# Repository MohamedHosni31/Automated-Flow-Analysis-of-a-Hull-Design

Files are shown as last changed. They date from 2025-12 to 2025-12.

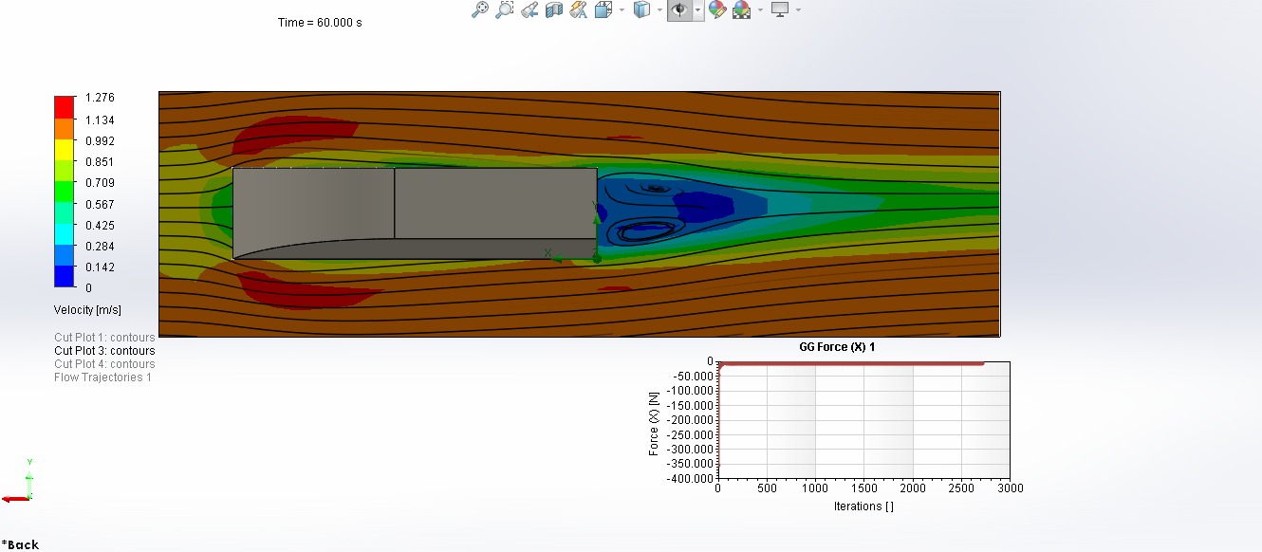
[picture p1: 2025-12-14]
2nd.jpg

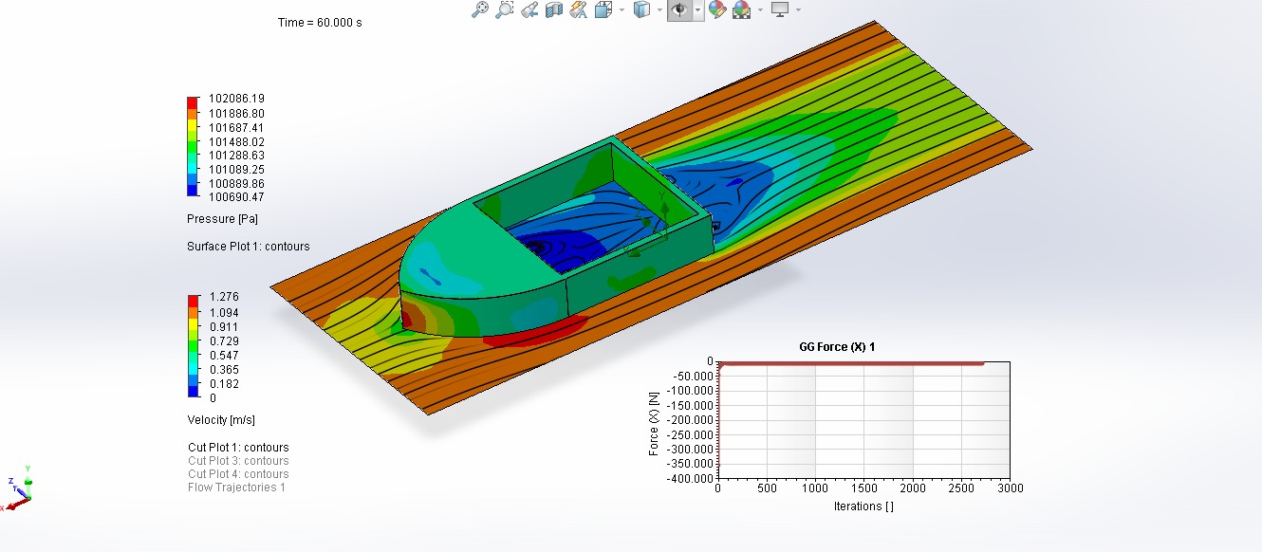
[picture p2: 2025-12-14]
1st.jpg

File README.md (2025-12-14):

# Automated Flow Analysis of a Hull Design

## 📌 Project Overview
This project involves the design and automated flow analysis of a small boat hull to evaluate fluid behavior around the structure. The project was developed at Alexandria University to demonstrate fundamental concepts of fluid mechanics, flow visualization, and design automation.

## 🎓 Academic Context
- Institution: Alexandria University
- Project Type: Mechanical Engineering Academic Project

## 🛠 Tools & Software
- SolidWorks
- SolidWorks Flow Simulation
- DC Motor (Propulsion Concept)

## ⚙ System Description
- Designed a small-scale boat hull capable of carrying a beverage can.
- Integrated a DC motor concept to enable forward motion.
- Performed flow analysis to study fluid behavior around the hull.
- Automated flow simulations to visualize pressure and velocity distribution.
- Evaluated hydrodynamic performance based on flow results.

## 📊 Key Outcomes
- Successful hull design with stable buoyancy.
- Visualization of flow patterns around the hull.
- Pressure and velocity distribution analysis.
- Demonstrated the impact of hull geometry on fluid flow.

## 📂 Project Contents
- Hull CAD model
- Flow simulation results
- Screenshots and visual outputs
- Project documentation

## 🎯 Skills Demonstrated
Fluid Mechanics · Flow Simulation · SolidWorks · Hull Design · Engineering Analysis · Automation

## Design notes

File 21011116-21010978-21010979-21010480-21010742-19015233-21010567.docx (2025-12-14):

Designing a Model Ship

NORMANDY 2

Presented By:

كريم ايهاب حمادة عبد الرؤوف 21010979

محمد حسني محمد ابراهيم 21011116

كريم السيد محمد محمد سريح 21010978

حنين اسامة محمد احمد 21010480

عبدالرحمن سيد احمد كامل 21010742

احمد رضا بسيوني السيد 19015233

زياد حسام محمد السعيد عثمان 21010567

Presented To:

Dr. Yasser Abuouf

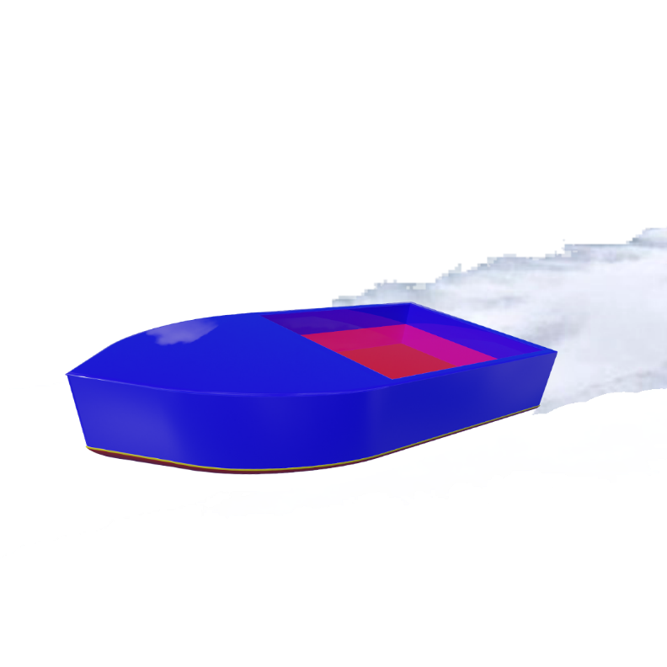
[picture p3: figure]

# Abstract

As it is required to build a ship with the ability to carry a standard cargo load of 1 can of soft drink (330ml) and must be stable in both cases loaded or unloaded. As a cooperative team, we fulfilled the requirements with an extraordinary outcome “Normandy 2”.

# Design Evolution

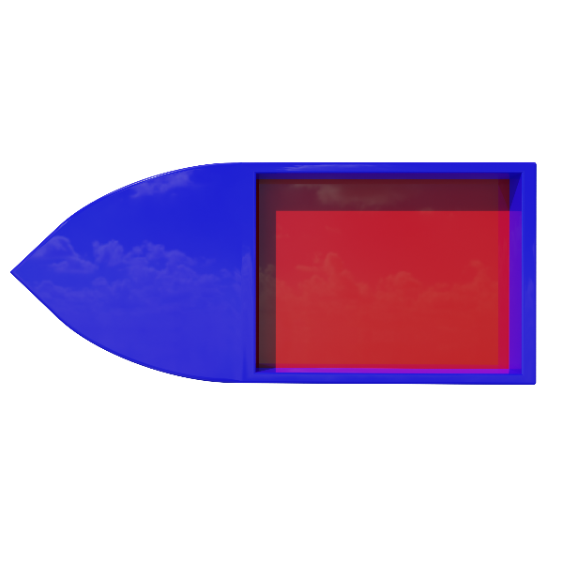
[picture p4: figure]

Phases were tackled by the team members to develop a fruitful result beginning with brainstorming and collaboration where we shared our ideas and developed them together followed by the illumination phase where we put the strategy, the costs, material selection, and the timeline to get the work done due to the set deadline. As everything comes to an end, implementation was our last to make ideas real and test the creation.

# Frame Design

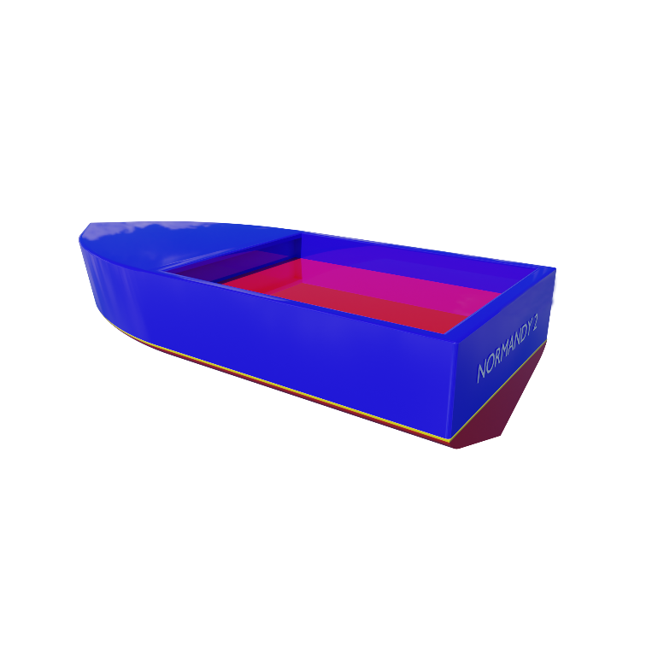
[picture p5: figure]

The boat’s frame was carefully designed to be stable loaded and unloaded. For fixations, a squared groove was made to maintain the components. The unloaded boat’s dimensions are 36 cm in length and 20 cm in width, 1598.16883 cm³ in volume, and 3689.3515 cm² in area, where its height from the hull to the waterline is 1.4 cm. These dimensions include the likes of the motor, the propeller, and the battery. When the can is included the height of the water line increases to 2.6 cm.

# Material Selection

Foam has proved its ability in compromising strength to hold the load and other components and being stable while loaded and unloaded. Foam appeared to be the most cost-effective compared to other materials such as wood or plastic polymers.

# Calculations

Immersed Volume :

Unloaded :

Boat Mass = 470 grams, Seawater Density = 1030 kg/m³, Immersed Height = 1.4 cm

Volume_(immersed) × ρ_(fluid) =Volume_(body) × ρ_(solid)

V_(imm) =(m_(body))/(ρ_(fluid))=0.47/1030

V_(imm) =4.56 × 10^(-4) m^3

Loaded :

Boat Mass = 840 grams, Seawater Density = 1030 kg/m³, Immersed Height = 2.6 cm

Volume_(immersed) × ρ_(fluid) =Volume_(body) × ρ_(solid)

V_(imm) =(m_(body))/(ρ_(fluid))=0.84/1030

V_(imm) =8.155 × 10^(-4) m^3

Stability Check :

Unloaded :

Boat Mass = 470 grams, Center of Gravity (From Solidworks) = 50 mm

Center of Buoyancy (From Solidworks) = 12.48 mm, Volume immersed = 4.56 x 10^(-4) m^3

Second moment of area (From Solidworks) = 197200620.36 mm⁴

BG=KG-KB=50-12.48

BG=37.52 mm

BM=I/(V_(imm))=(197200620.36 × (10^(-3) )^4)/(4.56 × 10^(-4))

BM=0.432 m=432.46 mm

BM>BG → ∴Boat is stable

Loaded :

Boat Mass = 840 grams, Center of Gravity (From Solidworks) = 50 mm

Center of Buoyancy (From Solidworks) = 22 mm, Volume immersed = 8.16 x 10^(-4) m^3

Second moment of area (From Solidworks) = 143052480.16 mm⁴

BG=KG-KB=50-22

BG=28 mm

BM=I/(V_(imm))=(143052480.16 × (10^(-3) )^4)/(8.16 × 10^(-4))

BM=0.175 m=175.42 mm

BM>BG → ∴Boat is stable

Ship Resistance (Drag Force) :

Unloaded :

Seawater Density = 1030 kg/m³, Velocity (Calculated after trials) = 0.4667609 m/s,

Wetted Area = 0.11401175 m², Water’s Kinematic Viscosity = 1 mm²/s

Re=(Velocity × Length)/(Kinematic viscosity)=(0.4667609×0.36)/(1 × 10^(-6))=168033.924

Resistance coefficient=0.075/((log_10 Re-2)^2)=7.2 × 10^(-3)

Resistance=Cf ×1/2 × ρ × v^2 × A_(imm)

Res=7.2 × 10^(-3) ×1/2 × 1030 × 0.4667609^2 ×0.11401175

Resistance=0.0921 N

Loaded :

Seawater Density = 1030 kg/m³, Velocity (Calculated after trials) = 0.37362729 m/s,

Wetted Area = 0.18644327 m², Water’s Kinematic Viscosity = 1 mm²/s

Re=(Velocity × Length)/(Kinematic viscosity)=(0.37362729×0.36)/(1 × 10^(-6))=134505.82

Resistance coefficient=0.075/((log_10 Re-2)^2)=7.66 × 10^(-3)

Resistance=Cf ×1/2 × ρ × v^2 × A_(imm)

Res=7.66 x 10^(-3) ×1/2 × 1030 × 0.37362729^2 × 0.18644327

Resistance=0.1027 N

Flow Simulation :


Drag Force = 0.09 Newtons

Cost Analysis

Component | Description | Status | Cost
Foam sheet | 142 gm | New | 300.0
Dc motor | Dc motor with gearbox 9V | New | 140.0
Battery | Camelion battery 9V 6F22 | New | 20.0
Battery cap | Battery cap 9V | New | 2.0
Propeller | Red plastic 4 blades propeller | New | 15.0
Switch | On/off red switch 3 pins 6A 250VAC 15x21mm | New | 2.0
| | | 479.0

Technical report Normandy 2

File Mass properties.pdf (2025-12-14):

Mass properties of Untitled.step Configuration: Default
Coordinate system: Coordinate System1

Mass = 313.07 grams

Volume = 1598168.83 cubic millimeters

Surface area = 368935.15 square millimeters

Center of mass: ( millimeters )
X = 0.00
Y = 48.69
Z = -157.03

Principal axes of inertia and principal moments of inertia: ( grams * square millimeters ) Taken at the center of mass.
Ix = ( 0.00, -0.04, 1.00) | Px = 1358303.16
Iy = ( 1.00, 0.00, 0.00) | Py = 3524942.91
Iz = ( 0.00, 1.00, 0.04) | Pz = 4413985.74

Moments of inertia: ( grams * square millimeters )
Taken at the center of mass and aligned with the output coordinate system. (Using positive tensor notation.)
Lxx = 3524942.91 | Lxy = 7.56Lxz = -39.52
Lyx = 7.56 Lyy = 4408124.89 | Lyz = -133695.74
Lzx = -39.52 | Lzy = -133695.74 | Lzz = 1364164.01

Moments of inertia: ( grams * square millimeters )
Taken at the output coordinate system. (Using positive tensor notation.)
Ixx = 11987176.84 | Ixy = -16.52 | Ixz = 38.15
Iyx = -16.52 | Iyy = 12128183.67 Iyz = -2527361.51
Izx = 38.15 | Izy = -2527361.51 | Izz = 2106339.17

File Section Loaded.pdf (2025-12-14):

Section properties of the selected face of Ship

Area = 62917.32 millimeters^2

Centroid relative to output coordinate system origin: ( millimeters ) X = 159.42
Y = 26.00
Z = 0.00

Moments of inertia of the area, at the centroid: ( millimeters ^ 4 ) Lxx = 188050419.75 Lxy = 0.00Lxz = 0.00 Lyx = 0.00 Lyy = 746043565.69 Lyz = 0.00 Lzx = 0.00Lzy = 0.00Lzz = 557993145.94

Polar moment of inertia of the area, at the centroid = 746043565.69 millimeters ^ 4

Angle between principal axes and part axes = 90.00 degrees

Principal moments of inertia of the area, at the centroid: ( millimeters ^ 4 )
Ix = 188050419.75
Iy = 557993145.94

Moments of inertia of the area, at the output coordinate system: ( millimeters ^ 4 )
LXX = 230582529.02 | LXY = 260783404.69LXZ = 0.00
LYX = 260783404.69 LYY = 2345023379.26 | LYZ = 0.00
LZX = 0.00 | LZY = 0.00 | LZZ = 2199505068.79

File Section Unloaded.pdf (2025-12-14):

Section properties of the selected face of 1

Area = 20454.29 millimeters^2

Centroid relative to assembly origin: ( millimeters ) X = -0.02
Y = 35.42
Z = 80.72

Moments of inertia of the area, at the centroid: ( millimeters ^ 4 ) Lxx = 197200620.36 Lxy = 0.00Lxz = -73834.95 Lyx = 0.00 Lyy = 287529577.91 Lyz = 0.00
Lzx = -73834.95 Lzy = 0.00Lzz = 90328957.56

Polar moment of inertia of the area, at the centroid = 287529577.91 millimeters ^ 4

Angle between principal axes and assembly coordinate axes = 0.04 degrees

Principal moments of inertia of the area, at the centroid: ( millimeters ^ 4 )
Ix = 90328906.55
Iy = 197200671.37

Moments of inertia of the area, at the output coordinate system: ( millimeters ^ 4 )
LXX = 356147207.57 | LXY = -12553.95 | LXZ = 45226.00
LYX = -12553.95 | LYY = 420811869.72 LYZ = 58485868.12
LZX = 45226.00 | LZY = 58485868.12 LZZ = 115993265.24

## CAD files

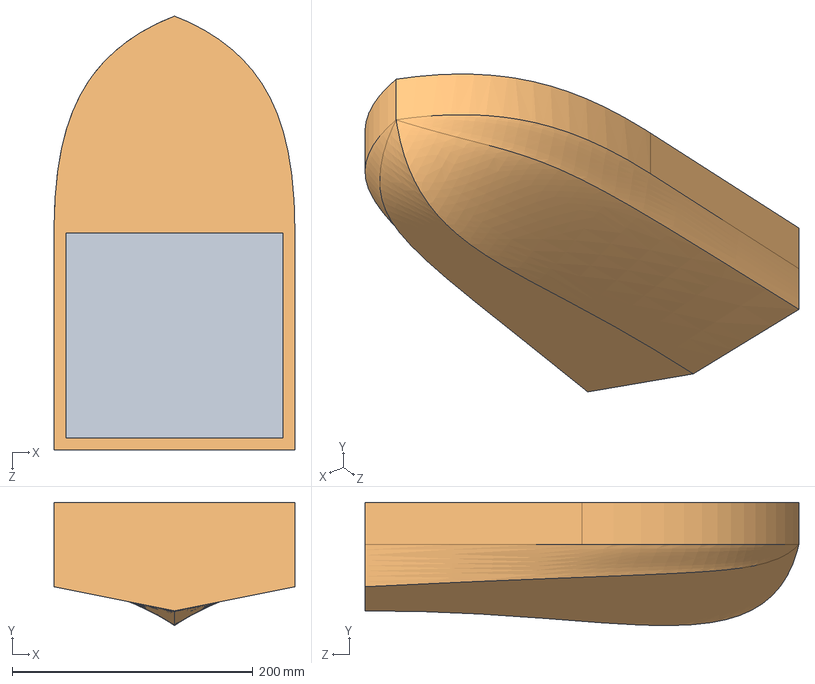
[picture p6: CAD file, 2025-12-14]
model.SLDASM
200.0 x 102.3 x 360.0 mm
Component1.step
(Unsaved).step
(Unsaved)-0.step

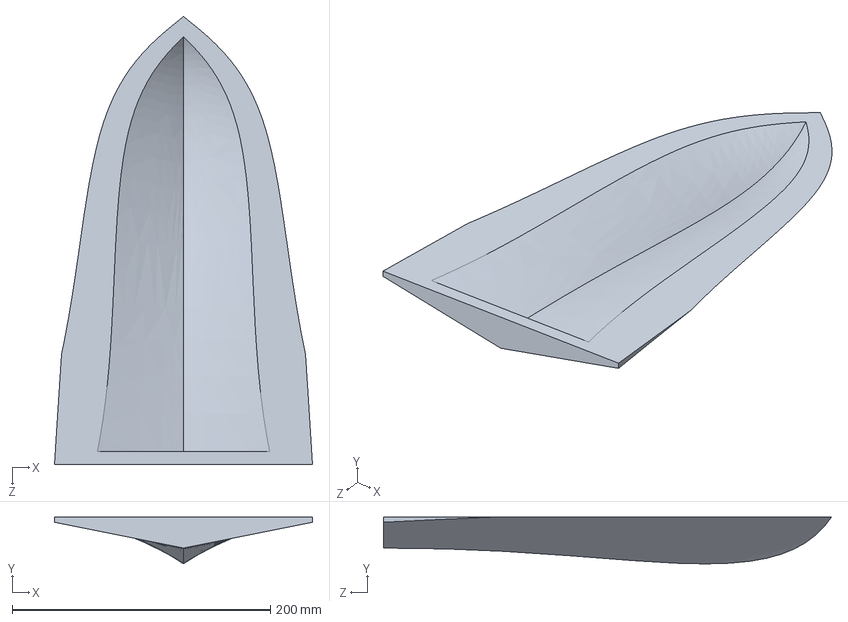
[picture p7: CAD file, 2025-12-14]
1.SLDASM
200.0 x 36.3 x 347.3 mm

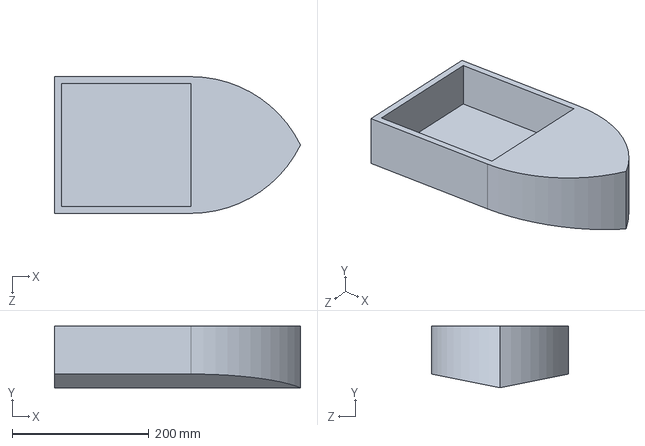
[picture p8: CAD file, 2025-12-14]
Ship.SLDPRT
360.0 x 90.0 x 200.0 mm

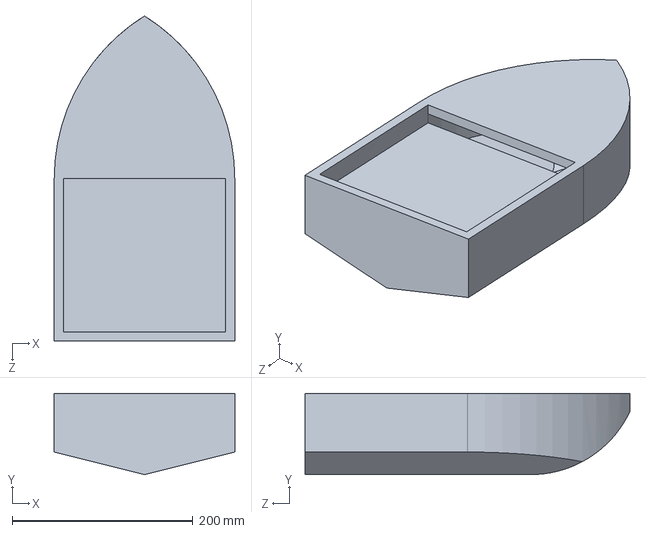
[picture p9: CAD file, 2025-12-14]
water.SLDPRT
200.0 x 90.0 x 360.0 mm

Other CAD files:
Untitled.step
Untitled.SLDASM
